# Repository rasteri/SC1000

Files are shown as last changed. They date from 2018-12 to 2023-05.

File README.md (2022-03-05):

# SC1000
## Open-source portable digital scratch instrument

This github holds source code and CAM files for the SC1000.

The SC1000 is a portable digital scratch instrument which loads samples and beats from a USB stick. At less than the size of three stacked DVD cases, it’s probably the smallest integrated portablist solution ever. Despite this, the software and hardware have been carefully tuned and optimised, and it’s responsive enough for even the most complex scratch patterns.

The device, including its enclosure, uses no custom parts apart from printed circuit boards. It will be possible for anyone with a bit of electronics know-how to build one, and I hope other makers in the portablist scene will be interested in manufacturing some.

The build tutorial video can be found here : https://www.youtube.com/watch?v=t1wy7IFSynY

## Usage ##

Simply switch on SC1000 with a valid USB stick in, and after a few seconds it will start playing the first beat and sample on the USB stick. Plug in some headphones or a portable speaker, adjust the volume controls to your liking, and get skratchin!

*Pressing* the **beat/sample down** button will select the next file in the current folder, and *holding* the button will skip to the next folder.

Note that you shouldn't touch the jog wheel while you are turning the device on - this is because the SC1000 does a short calibration routine. Leave it a few seconds before touching it.

## USB Folder layout ##

The SC1000 expects the USB stick to have two folders on it - **beats** and **samples**. Note that the names of these folders *must* be in all-lowercase letters.

The beats and samples folders should in turn contain a number of subfolders, to organise your files into albums. Each of these subfolders should contain a number of audio files, in **mp3** or **wav** format. For example, you might have a folder layout like : 

* beats/Deluxe Shampoo Breaks/beat1.mp3
* beats/Deluxe Shampoo Breaks/beat2.mp3
* beats/Deluxe Shampoo Breaks/beat3.mp3
* beats/Gag Seal Breaks/beat1.wav
* beats/Gag Seal Breaks/beat2.wav
* beats/Gag Seal Breaks/beat3.wav
* samples/Super Seal Breaks/01 - Aaaah.wav
* samples/Super Seal Breaks/02 - Fresh.wav
* samples/Enter the Scratch Game vol 1/01 - Aaaah Fresh.wav
* samples/Enter the Scratch Game vol 1/02 - Funkyfresh Aaaah.wav
* samples/Enter the Scratch Game vol 1/03 - Funkydope Aaaah.wav

Optionally, you can put an updated version of xwax on the root of the USB stick, and the SC1000 will run it instead of the internal version. This gives a very easy way to update the software on the device.

SC implementation chart

Demo Video (https://www.youtube.com/watch?v=ReuCnZciOf4)

The folders are as follows : 
* **Firmware** - Source code for the input processor. This handles the pots, switches and capacitive touch sensor, and passes the information on to the main processor.
* **OS** - SD card images and buildroot configs for the operating system that runs on the main processor.
* **Software** - Source code for the modified version of xwax running on the main SoC.
* **Hardware** - Schematics and gerbers for the main PCB and enclosure (which is made of PCBs)

## Tech Info ##

The device is based around the Olimex A13-SOM-256 system-on-module, which in turn uses an Allwinner A13 ARM Cortex A8 SoC. The sensing of the scratch wheel is handled by an Austria Microsystems AS5601 magnetic rotary sensor, and the other inputs are processed via a Microchip PIC18LF14K22 MCU. The whole unit is powered via USB, and optionally includes the ability to fit a power bank inside the enclosure.

## Build guide : 

### Assembly video ###

A video covering most of this information can be found at https://www.youtube.com/watch?v=t1wy7IFSynY

### Ingredients

* **Main PCB and components** - Board files are in [hardware](./hardware) and can be ordered from somewhere like https://jlcpcb.com/
* **Components** - Bill of Materials is in [hardware/](./hardware) and can be ordered from Mouser
* **A13 System-on-Module** - Available from https://www.olimex.com/Products/SOM/A13/A13-SOM-256/, connects to the main PCB via 0.05" headers
* **SD Card** - To hold the operating system. It only needs 200Mb so just get the smallest card you can find
* **Enclosure parts** - The enclosure is made from PCBs and aluminium supports. Gerber files are in *./hardware/gerbers/Enclosure/*, aluminium supports are 20x10x156.8mm. The front and rear plates should be 1mm thick, the rest should be 1.6mm. I got mine from https://www.aluminiumwarehouse.co.uk/20-mm-x-10-mm-aluminium-flat-bar, they even cut it for me.
* **Jogwheel parts** - The jogwheel itself is a gold-plated PCB, available in [hardware/gerbers/Jog Wheel](./hardware/gerbers/Jog%20Wheel). Mine is made from 0.6mm thick board, you can choose the thickness you prefer. You'll also need M8 bearing/hex bolt/nuts/washers, and a diametrically polarized magnet from https://www.kjmagnetics.com/proddetail.asp?prod=D42DIA-N52. The bearing I used is available at https://uk.rs-online.com/web/p/ball-bearings/6189957/
* **Mini innoFADER** - the OEM model (for example found in the innoFADER Mini DUO pack) is fine, but a Mini innoFADER Plus has  better performance

### Method ###

* **Order** the Main and Enclosure PCBs, the components, the A13 SoM, and SD Card, and the Aluminium bar. I recommend using ENIG coating for the Jogwheel as you don't really want to be touching solder all day.

* **Assemble the Main PCB.** I recommend assembling/testing the 3.3v power section first, so you don't blow all the other components. Don't connect the A13 module yet.

* **Flash the input processor with its firmware** through connector J8. You will need a PIC programmer, such as the Microchip Pickit 3. The firmware hex file is [firmware/firmware.hex](./firmware/firmware.hex)

* **Transfer the operating system to the SD card.** You will need an SD card interface, either USB or built-in to your PC. You can use dd on Linux/MacOS or Etcher on Windows to transfer the image. The image is [os/sdcard.img.gz](./os/sdcard.img.gz)

* **Insert the SD card in the A13 module, and attach the SoM to the main PCB.** Make sure it's the correct way round - the SD card should be right beside the USB storage connector on the rear of the SC1000.

* **Connect a USB power source, and power up the unit to test** - the A13 module's green light should blink a few times before remaining on.

* **Assemble the jogwheel** - glue the bearing into the hole in the top plate of the enclosure. Now glue the magnet to the tip of the M8 bolt. Attach the jogwheel to the bearing using the bolt/nut/washer. Solder a wire to the outside of the bearing to act as a capacitive touch sensor.

* **Connect** the fader to J1, capacitive touch sensor to J4, and (optionally) a small internal USB power bank to J3. If you don't use an internal power bank, put two jumpers horizontally across J3 to allow the power to bypass it.

* **Test** - copy some beats and samples to a USB stick, and see if they play. Check below for how to structure the folders on the USB stick.

* **Assemble the enclosure** - drill and tap M3 holes in the aluminium, and screw the whole enclosure together. Make sure the magnet at the end of the jogwheel bolt is suspended directly above the rotary sensor IC.

## License ##

Copyright (C) 2018 Andrew Tait <rasteri@gmail.com>

This program is free software; you can redistribute it and/or
modify it under the terms of the GNU General Public License
version 2, as published by the Free Software Foundation.

This program is distributed in the hope that it will be useful, but
WITHOUT ANY WARRANTY; without even the implied warranty of
MERCHANTABILITY or FITNESS FOR A PARTICULAR PURPOSE. See the GNU
General Public License version 2 for more details.

You should have received a copy of the GNU General Public License
version 2 along with this program; if not, write to the Free
Software Foundation, Inc., 51 Franklin Street, Fifth Floor, Boston,
MA 02110-1301, USA.

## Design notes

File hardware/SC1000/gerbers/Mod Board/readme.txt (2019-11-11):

This is a board to convert the v0.1 PCB to v0.2 by adding the required filters to the audio outputs.

It just solders directly underneath the 3.5mm audio jack.

You probably want to order it in thinner-than-normal PCB material (0.6 worked for me) and make sure your fab house can do castellated holes.

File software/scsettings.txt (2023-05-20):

#######################
# SC1000 config file #
######################
# Any lines beginning with # are ignored

###################
# General Options #
###################
#
# Fader thresholds for hysteresis
# You might need to adjust these for different faders
# faderopenpoint should always be 
# more than faderclosepoint

# Value required to open the fader when it's closed
faderopenpoint=5

# Value required to close the fader when it's opened
faderclosepoint=3

# 0 to disable platter, default 1 (enabled)
platterenabled=1

# Ratio of platter movement to sample movement
# 4096 = 1 second for every platter rotation
# 3072 = equivalent to 45rpm record (default)
# 2275 = equivalent to 33rpm
platterspeed=2275

# How long the stop button takes to stop the track
# Higher is longer, default = 3000
brakespeed=3000

# Pitch range % of pitch bend MIDI command, default 50%
pitchrange=50

# How long to delay before looking for MIDI devices
# Useful if your MIDI device takes a long time to initialize
# Or to give you time to switch your phone to MIDI mode
mididelay=5

# Set this to 1 or 2 to make the fader cut the beats
# 1 will cut on the left, 2 will cut on the right
cutbeats=0

####################
#   GPIO Mapping   #
####################
#
# This section is used to wire up buttons.
# These can be either directly wired to the Olimex module,
# or on an external MCP23017 GPIO expander
# Format is : 
# gpio=port,pin,pull,edge,action

# port is 0 for MCP23017, or 123456 for ports BCDEFG of A13 on Olimex
# pin number- for MCP23017, A0-A7 is 0-7 and B0-B7 is 8-15
# pull is 1 for pullup, 2 for pulldown
# edge is 1 for pressing edge, 2 for holding action, 3 for pressed while shifted, 4 for held while shifted, 0 for releasing edge
# action is one of :
# 
# (replace x with 0 for beats or 1 for samples) :
# CHx_CUE - Set and trigger cue points
# CHx_SHIFTON - Activate shift mode (ignores x)
# CHx_SHIFTOFF - Deactivate shift mode (also ignores x)
# CHx_STARTSTOP - Start or Stop the track
# CHx_NOTEy - Change the pitch musically, replace y with the note number (60 being 0%)
# CHx_GND - make the pin an output and set it low - used to provide additional ground connections (ignores x)
# gpio=port,pin,pull,edge,action

#### SC500 Buttons ####
# Detection pin
gpio=6,11,1,1,CH0_SC500

# Shift
gpio=2,9,1,1,CH0_SHIFTON
gpio=2,9,1,0,CH0_SHIFTOFF

# Beat Transport
gpio=2,14,1,1,CH0_PREVFILE
gpio=2,14,1,2,CH0_PREVFOLDER
gpio=2,14,1,3,CH0_RANDOMFILE

gpio=2,13,1,1,CH0_STARTSTOP

# even though this is on a beat button it still affects sample
gpio=2,13,1,3,CH1_JOGREVERSE

gpio=2,10,1,1,CH0_NEXTFILE
gpio=2,10,1,2,CH0_NEXTFOLDER
gpio=2,10,1,3,CH0_JOGPIT
gpio=2,10,1,0,CH0_JOGPSTOP

# Beat Volume Buttons
gpio=4,5,1,1,CH0_VOLUP
gpio=4,5,1,2,CH0_VOLUHOLD
gpio=4,4,1,1,CH0_VOLDOWN
gpio=4,4,1,2,CH0_VOLDHOLD

# Sample Transport
gpio=2,5,1,1,CH1_PREVFILE
gpio=2,5,1,2,CH1_PREVFOLDER
gpio=2,5,1,3,CH1_JOGPIT
gpio=2,5,1,0,CH1_JOGPSTOP

gpio=2,6,1,1,CH1_STARTSTOP
gpio=2,6,1,3,CH1_RECORD

gpio=2,8,1,1,CH1_NEXTFILE
gpio=2,8,1,2,CH1_NEXTFOLDER
gpio=2,8,1,3,CH1_RANDOMFILE

# Sample volume buttons
gpio=1,10,1,1,CH1_VOLUP
gpio=1,10,1,2,CH1_VOLUHOLD
gpio=1,4,1,1,CH1_VOLDOWN
gpio=1,4,1,2,CH1_VOLDHOLD

# Sample cue buttons
gpio=2,4,1,1,CH1_CUE
gpio=2,4,1,3,CH1_DELETECUE
gpio=2,7,1,1,CH1_CUE
gpio=2,7,1,3,CH1_DELETECUE
gpio=2,11,1,1,CH1_CUE
gpio=2,11,1,3,CH1_DELETECUE
gpio=2,12,1,1,CH1_CUE
gpio=2,12,1,3,CH1_DELETECUE

#### Expansion port J7 ####
gpio=6,10,1,1,CH0_SHIFTON
gpio=6,10,1,0,CH0_SHIFTOFF
gpio=1,15,1,1,CH0_STARTSTOP
gpio=1,16,1,1,CH1_STARTSTOP

gpio=2,3,1,1,CH1_CUE
gpio=2,0,1,1,CH1_CUE
gpio=2,2,1,1,CH1_CUE
gpio=2,1,1,1,CH1_CUE

gpio=2,3,1,3,CH1_DELETECUE
gpio=2,0,1,3,CH1_DELETECUE
gpio=2,2,1,3,CH1_DELETECUE
gpio=2,1,1,3,CH1_DELETECUE

#### MCP23017 Buttons ####
gpio=0,0,0,1,CH0_GND

gpio=0,1,1,1,CH1_CUE
gpio=0,2,1,1,CH1_CUE
gpio=0,3,1,1,CH1_CUE
gpio=0,4,1,1,CH1_CUE
gpio=0,5,1,1,CH1_CUE
gpio=0,6,1,1,CH1_CUE
gpio=0,7,1,1,CH1_CUE

gpio=0,1,1,3,CH1_DELETECUE
gpio=0,2,1,3,CH1_DELETECUE
gpio=0,3,1,3,CH1_DELETECUE
gpio=0,4,1,3,CH1_DELETECUE
gpio=0,5,1,3,CH1_DELETECUE
gpio=0,6,1,3,CH1_DELETECUE
gpio=0,7,1,3,CH1_DELETECUE

gpio=0,8,1,1,CH1_STARTSTOP
gpio=0,9,1,1,CH0_SHIFTON
gpio=0,9,1,0,CH0_SHIFTOFF 
gpio=0,10,1,1,CH1_CUE
gpio=0,10,1,3,CH1_DELETECUE
gpio=0,11,1,1,CH0_STARTSTOP
gpio=0,12,0,1,CH1_GND
gpio=0,13,1,1,CH1_CUE
gpio=0,14,1,1,CH1_CUE
gpio=0,15,1,1,CH1_CUE
gpio=0,13,1,3,CH1_DELETECUE
gpio=0,14,1,3,CH1_DELETECUE
gpio=0,15,1,3,CH1_DELETECUE

################
# MIDI Mapping #
################
#
# Format is :
# Status,channel,data,edge, action
# 
# Status can be : 
# 8 - Note OFF (will also match zero-velocity Note ON)
# 9 - Note ON
# 11 - Control Change
# 14 - Pitch Bend
#
# Channel is the MIDI channel of the incoming MIDI message
#
# Data is the note or CC number - set to "255" to bind to ALL notes of a particular channel
#
# Action can be (replace x with 0 for beats or 1 for samples) :
# CHx_CUE - Set and trigger cue points
# CHx_SHIFTON - Activate shift mode (ignores x)
# CHx_SHIFTOFF - Deactivate shift mode (also ignores x)
# CHx_STARTSTOP - Start or Stop the track
# CHx_PITCH - Change the speed of the track
# CHx_NOTEy - Change the pitch musically, replace y with the note number (60 being 0%)

#### LEMUR PRESET, normally hardcoded ####

# CC 0 of channels 0/1 is volume
midii=11,0,0,1,CH0_VOLUME
midii=11,1,0,1,CH1_VOLUME

# Pitch bend on channels 0 and 1 is pitch

midii=14,0,0,1,CH0_PITCH
midii=14,1,0,1,CH1_PITCH

# notes on channels 0 and 1 are cue points
midii=9,0,255,1,CH0_CUE
midii=9,1,255,1,CH1_CUE

# Also add the delete cue command for shift modifier
midii=9,0,255,3,CH0_DELETECUE
midii=9,1,255,3,CH1_DELETECUE

# Notes on channel 3 are C1-style notes
midii=9,3,255,1,CH1_NOTE

# Channel 4 has various other commands mapped to its notes
# Notes 0-1 = start stop
midii=9,4,0,1,CH0_STARTSTOP
midii=9,4,1,1,CH1_STARTSTOP

# Notes 2-3 = Next file
midii=9,4,2,1,CH0_NEXTFILE
midii=9,4,3,1,CH1_NEXTFILE

# Notes 4-5 = Next folder
midii=9,4,4,1,CH0_NEXTFOLDER
midii=9,4,5,1,CH1_NEXTFOLDER

# Notes 6-7 = Prev file
midii=9,4,6,1,CH0_PREVFILE
midii=9,4,7,1,CH1_PREVFILE

# Notes 8-9 = Prev folder
midii=9,4,8,1,CH0_PREVFOLDER
midii=9,4,9,1,CH1_PREVFOLDER

# Notes 10-11 = Random file
midii=9,4,10,1,CH0_RANDOMFILE
midii=9,4,11,1,CH1_RANDOMFILE

# Note 126 = record
midii=9,4,126,1,CH0_RECORD

# Note 127 = shift
midii=9,4,127,1,CH1_SHIFTON
midii=8,4,127,3,CH1_SHIFTOFF

# Status,channel,data,edge,action

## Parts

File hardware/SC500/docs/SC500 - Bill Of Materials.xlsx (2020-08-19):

 | Bill of Materials
 | SC500 Main PCB
Designator(s) | Qty | Manufacturer | Manufacturer Part Number | Description | Package | Type | Mouser Part Number
C1 | 1 | Taiyo Yuden | UMK316AB7475KL-T | Capacitor Ceramic 1206 4.7uF 16V X7R | 1206 | SMD | 963-UMK316AB7475KL-T
C2 | 1 | TDK | C3216X7R1C106M160AC | Capacitor Ceramic 1206 10uF 10v X7R | 1206 | SMD | 810-C3216X7R1C106M
C3, C4, C5, C6, C7, C8, C9 | 7 | Wurth Electronics | 885012208058 | Capacitor Ceramic 1206 0.1uF 10v X7R | 1206 | SMD | 710-885012208058
J1 | 1 | Amphenol FCI | 861400041LO1705LF | Connector Header 4x1 2.54mm RA | TH4X1 | THRU-HOLE | 649-86140041LO1705LF
J2 | 1 | Amphenol FCI | UE27AC54100 | Connector USB Type A | UE27AC54100 | THRU-HOLE | 523-UE27-AC54-100
J3 | 1 | Amphenol FCI | 68021-404HLF | Connector Header 2x2 2.54mm RA | TH2X2 | THRU-HOLE | 649-68021-404HLF
J4 | 1 | Amphenol FCI | 861400021LO1705LF | Connector Header 2x1 2.54mm RA | TH2X1 | THRU-HOLE | 649-86140021LO1705LF
J41, J43 | 2 | Amphenol FCI | 20021121-00010T4LF | Connector Header 2x5 1.27mm | SMT2X5 | SMD | 649-221121-00010T4LF
J42, J44 | 2 | Amphenol FCI | 20021121-00040T4LF | Connector Header 2x20 1.27mm | SMT2X20 | SMD | 649-221121-00040T4LF
J5 | 1 | Switchcraft | 35RAPC4BH3 | Connector 3.5MM Stereo Jack | 35RAPC4BH3 | THRU-HOLE | 502-35RAPC4BH3
J6 | 1 | TE Connectivity | 2108877-1 | Connector USB Type Micro-B | 2108877-1 | SMD + THRU-HOLE | 571-2108877-1
L1 | 1 | Taiyo Yuden | NR6028T2R2N | Inductor 6028 2.2uH 3.7A 26mOhm | 6028 | SMD | 963-NR6028T2R2N
R10, R11, R12, R13, R14 | 5 | Yageo | RC1206JR-134K7L | Resistor 1206 4.7K 1/4W 20% | 1206 | SMD | 603-RC1206JR-134K7L
R4, R6, R17 | 3 | Yageo | AC1206FR-0722RL | Resistor 1206 22R 1/4W 1% | 1206 | SMD | 603-AC1206FR-0722RL
R2 | 1 | Yageo | RC1206FR-07442KL | Resistor 1206 442K 1/4W 1% | 1206 | SMD | 603-RC1206FR-07442KL
R3 | 1 | Yageo | RC1206FR-07100KL | Resistor 1206 100K 1/4W 1% | 1206 | SMD | 603-RC1206FR-07100KL
S1, S2, S3, S4, S5, S7, S8, S9, S10, S11, S12 | 11 | TE Connectivity | FSM14JLH | Switch Tactile | FSM14JLH | THRU-HOLE | 506-FSM14JLH
S13, S14 | 2 | E-Switch | TL2243 | Switch Dual SPST, Dual | TL2243 | THRU-HOLE | 612-TL2243
U1 | 1 | ams | AS5601-ASOM | IC Rotary Sensor SOIC-8 | SOIC8 | SMD | 985-AS5601-ASOM
U2 | 1 | Texas Instruments | TLV62568DBVR | IC Buck Converter SOT23-5 | SOT-23-5 | SMD | TLV62568DBVR
U3 | 1 | Microchip | PIC18LF14K22-I/SO | IC MCU PIC18 | SOIC20 | SMD | 579-PIC18LF14K22I/SO

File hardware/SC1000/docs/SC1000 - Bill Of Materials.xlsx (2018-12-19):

 |  | Bill of Materials
 |  | SC1000 Main PCB
Item # | Designator(s) | Qty | Manufacturer | Manufacturer Part Number | Description | Package | Type | Mouser Part Number
1 | C1 | 1 | Taiyo Yuden | UMK316AB7475KL-T | Capacitor Ceramic 1206 4.7uF 16V X7R | 1206 | SMD | 963-UMK316AB7475KL-T
2 | C2 | 1 | TDK | C3216X7R1C106M160AC | Capacitor Ceramic 1206 10uF 10v X7R | 1206 | SMD | 810-C3216X7R1C106M
3 | C3, C6, C7, C8 | 4 | Wurth Electronics | 885012208058 | Capacitor Ceramic 1206 0.1uF 10v X7R | 1206 | SMD | 710-885012208058
4 | J1 | 1 | Amphenol FCI | 861400041LO1705LF | Connector Header 4x1 2.54mm RA | TH4X1 | THRU-HOLE | 649-86140041LO1705LF
5 | J2 | 1 | Molex | 48204-0001 | Connector USB Type A | 48204-0001 | THRU-HOLE | 538-48204-0001
6 | J3 | 1 | Amphenol FCI | 68021-404HLF | Connector Header 2x2 2.54mm RA | TH2X2 | THRU-HOLE | 649-68021-404HLF
7 | J4 | 1 | Amphenol FCI | 861400021LO1705LF | Connector Header 2x1 2.54mm RA | TH2X1 | THRU-HOLE | 649-86140021LO1705LF
8 | J41, J43 | 2 | Amphenol FCI | 20021121-00010T4LF | Connector Header 2x5 1.27mm | SMT2X5 | SMD | 649-221121-00010T4LF
9 | J42, J44 | 2 | Amphenol FCI | 20021121-00040T4LF | Connector Header 2x20 1.27mm | SMT2X20 | SMD | 649-221121-00040T4LF
10 | J5 | 1 | Switchcraft | 35RAPC4BH3 | Connector 3.5MM Stereo Jack | 35RAPC4BH3 | THRU-HOLE | 502-35RAPC4BH3
11 | J6 | 1 | TE Connectivity | 2108877-1 | Connector USB Type Micro-B | 2108877-1 | SMD + THRU-HOLE | 571-2108877-1
12 | L1 | 1 | Taiyo Yuden | NR6028T2R2N | Inductor 6028 2.2uH 3.7A 26mOhm | 6028 | SMD | 963-NR6028T2R2N
13 | R1, R7, R8, R9, R10, R11, R12, R13, R14 | 9 | Yageo | RC1206JR-134K7L | Resistor 1206 4.7K 1/4W 20% | 1206 | SMD | 603-RC1206JR-134K7L
14 | R2 | 1 | Yageo | RC1206FR-07442KL | Resistor 1206 442K 1/4W 1% | 1206 | SMD | 603-RC1206FR-07442KL
15 | R3 | 1 | Yageo | RC1206FR-07100KL | Resistor 1206 100K 1/4W 1% | 1206 | SMD | 603-RC1206FR-07100KL
16 | R5, R15 | 2 | Bourns | PTV09A-2020S-B104 | Potentiometer 100K | PTV09A | THRU-HOLE | 652-PTV09A2020SB104
17 | S1 | 1 | E-Switch | PB400EEQR1BLK | Switch DPST | PB400 | THRU-HOLE | 612-PB400EEQR1BLK
18 | S2, S3 | 2 | E-Switch | TL2243 | Switch Dual SPST, Dual | TL2243 | THRU-HOLE | 612-TL2243
19 | U1 | 1 | ams | AS5601-ASOM | IC Rotary Sensor SOIC-8 | SOIC8 | SMD | 985-AS5601-ASOM
20 | U2 | 1 | Texas Instruments | TLV62568DBVR | IC Buck Converter SOT23-5 | SOT-23-5 | SMD | TLV62568DBVR
21 | U3 | 1 | Microchip | PIC18LF14K22-I/SO | IC MCU PIC18 | SOIC20 | SMD | 579-PIC18LF14K22I/SO

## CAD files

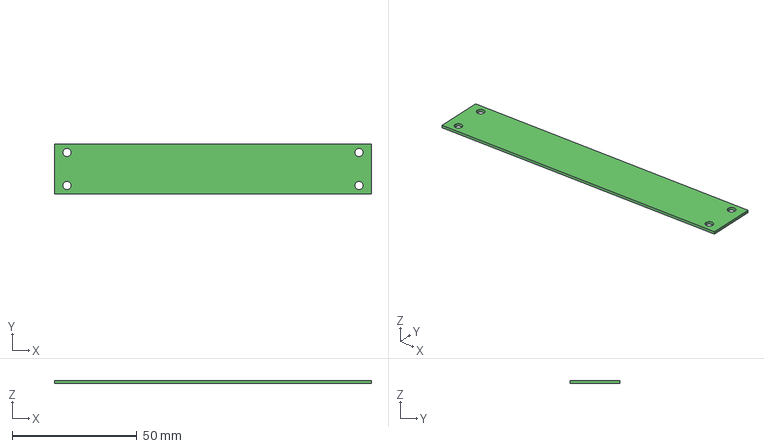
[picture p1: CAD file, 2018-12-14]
hardware/SC1000/step/frontplate.step
126.8 x 20.0 x 1.05 mm

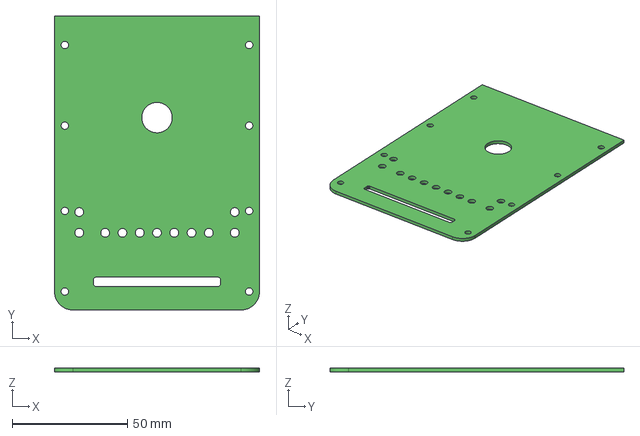
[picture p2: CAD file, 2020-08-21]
hardware/SC500/step/TOPPLATE.step
89.0 x 127.6 x 1.65 mm

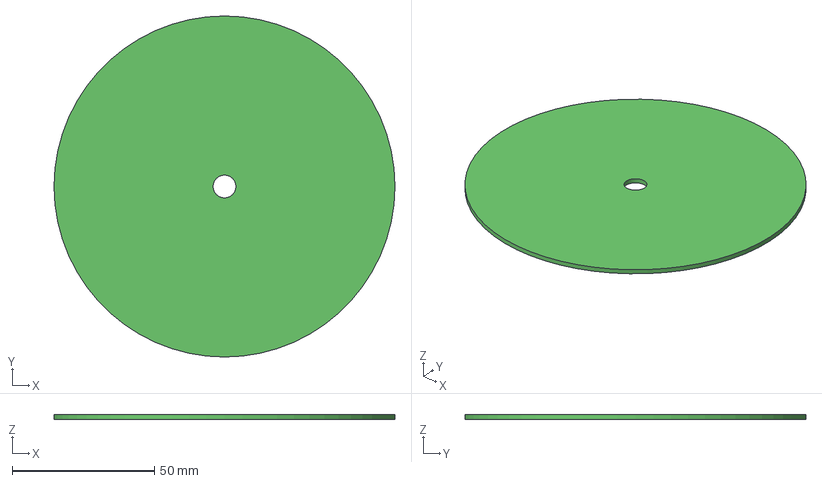
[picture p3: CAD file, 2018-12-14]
hardware/SC1000/step/jogwheel.step
120.0 x 120.0 x 1.65 mm

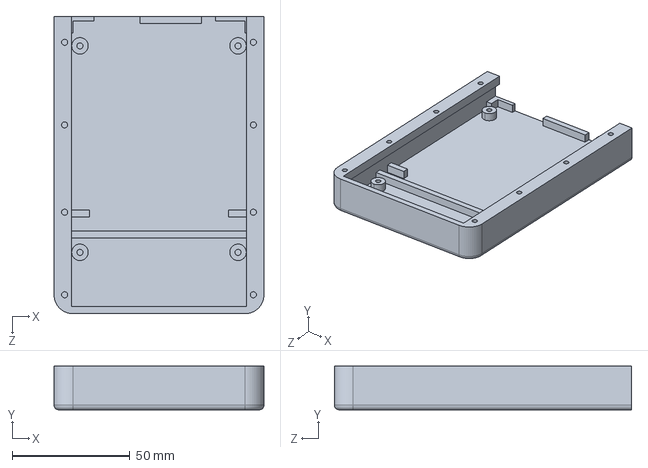
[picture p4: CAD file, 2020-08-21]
hardware/SC500/step/enclosure.STEP
89.0 x 18.5 x 126.0 mm

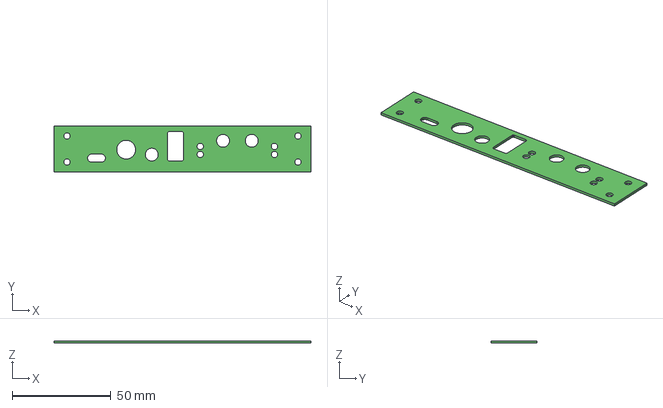
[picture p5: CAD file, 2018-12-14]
hardware/SC1000/step/backplate.step
130.0 x 23.2 x 1.12 mm

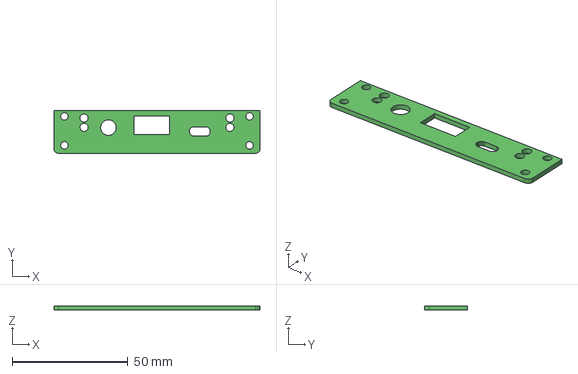
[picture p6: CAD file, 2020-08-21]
hardware/SC500/step/BACKPLATE.step
89.0 x 18.5 x 1.72 mm

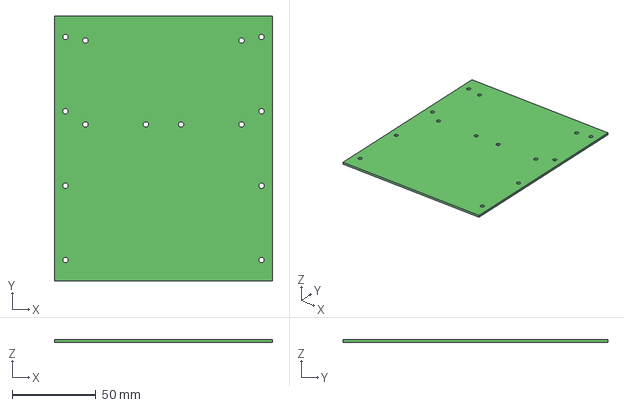
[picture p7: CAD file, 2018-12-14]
hardware/SC1000/step/bottomplate.step
130.0 x 157.8 x 1.65 mm

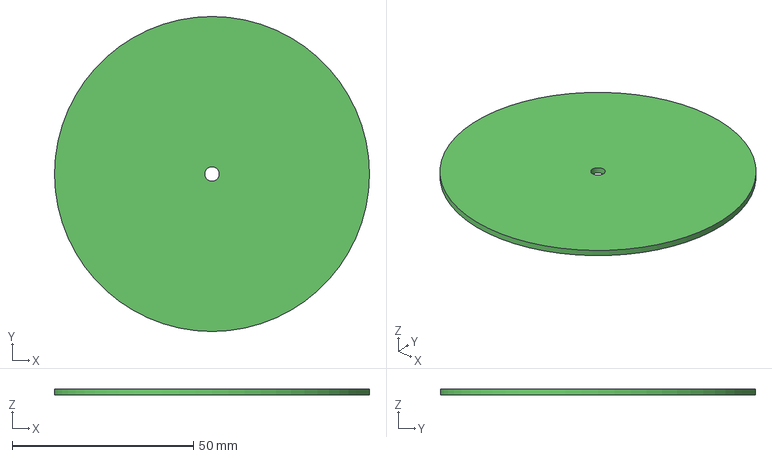
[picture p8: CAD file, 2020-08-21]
hardware/SC500/step/JogWheel.step
87.0 x 87.0 x 1.65 mm

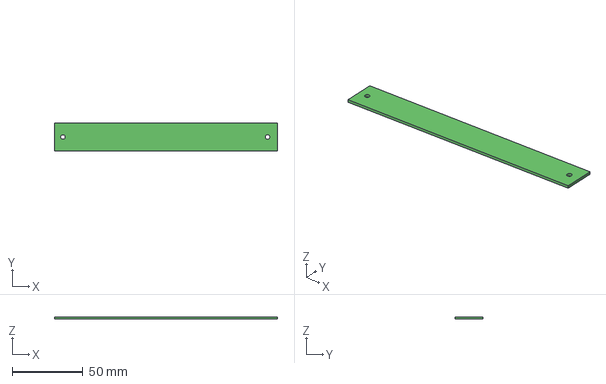
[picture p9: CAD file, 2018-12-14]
hardware/SC1000/step/sideplate.step
157.8 x 20.0 x 1.65 mm

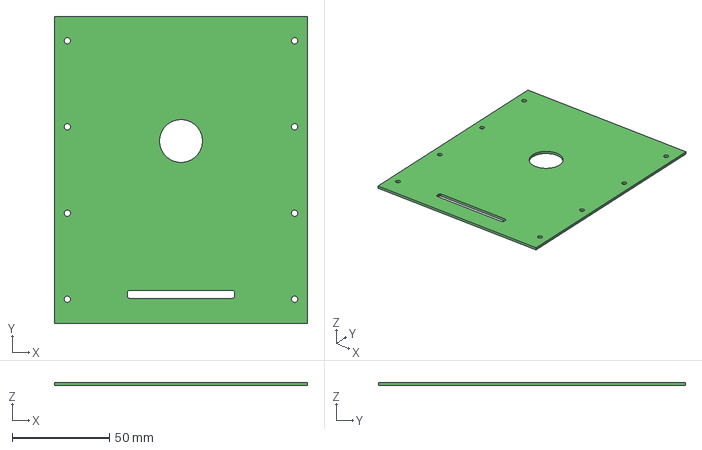
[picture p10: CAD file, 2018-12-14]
hardware/SC1000/step/topplate.step
130.0 x 157.8 x 1.65 mm

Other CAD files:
hardware/SC500/enclosure.STL

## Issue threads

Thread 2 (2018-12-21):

Jog Wheel PCB Dimensions

markprotas, 2018-12-21:
The dimensions of the jog wheel are a mystery to me- viewing the gerber files and attempting to run some dimension analysis on them, it seems like I get something like 1200 x 1200 mm, which certainly doesn't make any sense given the nature of the machine.  How can I figure out the actual jog wheel dimensions for fabrication?

rasteri, 2018-12-21:
It's 120mm X 120mm.

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

Closed 2019-09-09.

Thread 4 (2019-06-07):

No RC to ground filtering on headphone lines

DanKoloff, 2019-06-07:
Hello,

Lub from Olimex here. In your schematic I can see that there are no RC to ground groups on HPCOM and HPOUTL and HPOUTR. This might cause issues with some headphones or other audio equipment. Did you omit such on purpose?

Please perform some tests. Use the A13-OLinuXino-WIFI design as basis of the groups (left side of the schematic): https://github.com/OLIMEX/OLINUXINO/blob/master/HARDWARE/A13-OLinuXino/A13-OLinuXino_WIFI_Rev_H.pdf

I've also cut it out here:
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

Lub/OLIMEX

rasteri, 2019-06-07:
Hi Lub, good to hear from you.

Yes this was an oversight, but this was just really a development board to test software etc. As you say, there is some noise on the headphone output, particularly when the device is unpowered. I'm doing a second board revision with these changes plus some other stuff (ESD protection, better capacitive touch sensing).

Thanks for your input - if you notice any other problems let me know.

s3kn0tr0n1c, 2019-06-19:
Thanks for referring me to this after I contacted you about headphones out @DanKoloff .

I will modify my board this week as Im back from holiday and let you and @rasteri  know how it goes.

@rasteri  - Im the guy who you got to do the special firmware without touch sensor for. I have a couple of other minor issues that I'm sure you can fix too ;).

s3kn0tr0n1c, 2019-06-20:
Hi, Heres some of my current mods. Ive added the caps/resistors to output. Will check it out properly over next few days. See if there's any improvement plugging into line ins etc.  Here's a picture of mod you can refer others to if they want to see how I did it. Basically soldered a resistor to headphone pin, cap to resistor x3 . Then soldered 1 wire from nearby GND to all the caps.
-
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

I also added an area for my USB battery to be held so that unit can be an "all in one" unit. Heres how I did this using PCB spacers-

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

Also see this video showing battery mod.  - https://youtu.be/33W1NoMLeOI

After that I redone the side panels so finished item is like this -

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

Its now a nice little all in one unit self powered( a little thicker but no messy wires or USB battery hanging about) . All I gotta do is plug in headphones. Sweet.

s3kn0tr0n1c, 2019-06-20:
Now onto bug you @rasteri ;) Heres some issues(remember I'm on the "no touch sensor build")

1) When I load a new sample there is a distortion noise until I move the platter. You also get this if you go outwith the sample start/end points. Its quite extreme lol.

2) If you move the xfader to the cut in point. Like right  between off/on you get this weird effect where you are hearing the sample playing but robotic like. Im not sure if this has anything to do with my next issue, perhaps causing a bug.

3) Sticker drift. My reason for no touch sensor was to preserve the samples position to red marker on record. After a few fast movements and going round a full turn etc the sample no longer is at same position when you rewind record.

4) Not reloading sample when you change to it. Its like the sample is still stored in memory from before and plays from this position. It would be much better if it was reset/reloaded to play from the start again.

If 3 and 4 were sorted then I would be able to move record to 12oclock. Load in new sample and the samples would always be at same position , as they are on a regular record. (or on seratos -"sticker lock" feature, which is great.)

Must say if you could get these last things sorted this toy is GODLIKE ;).

Also I just discovered if you cut a beat correctly it auto loops as well. Ive been chopping 8-32 bar loops and they play like any skratch looper. Brilliant. Love it.

s3kn0tr0n1c, 2019-06-20:
Also I just used a standard ball bearing this time and hot melted it in place. Not sure if how well it will stay in place. Should be fine if i never sit on it lol.

Anyways FYI - you get flanged bearings that would be better that I may switch to later-

https://www.ebay.co.uk/itm/PREMIUM-MODEL-BEARINGS-FLANGED-TYPE-2RS-ZZ/200709759794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

These would also be easier to get to sit perfectly flat. Worth thinking about for future build guides ;)

s3kn0tr0n1c, 2019-06-20:
Ive did a video showing the bugs -

https://youtu.be/wtL78jQTReM

rasteri, 2019-09-09:
I have updated the schematics and gerbers to include the filters, and designed a mod board so this can be retro-fitted to the original dev boards.

The latest firmware rev also fixes the issues s3kn0tr0n1c talked about - available here
[sc1000previewbuild.zip](https://github.com/rasteri/SC1000/files/3591641/sc1000previewbuild.zip)

Closed 2019-09-09.

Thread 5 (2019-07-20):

Screws for USB connector J6

schmitts, 2019-07-20:
Which screw type is to use for the USB connector J6?

s3kn0tr0n1c, 2019-07-24:
I used M1.6mm. I bought them and the  nuts of ebay.

https://www.ebay.co.uk/itm/321168183114
https://www.ebay.co.uk/itm/111309628000

rasteri, 2019-09-09:
I used M1.4 screws and nuts. Best get em from ebay.

Closed 2019-09-09.

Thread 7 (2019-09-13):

Loud Static Bursts in XWAX

wowitsjack, 2019-09-13:
Scratching from the very beginning of a sample can often lead to horrific max volume static.

rasteri, 2019-09-13:
Have you tried the latest firmware? http://rasteri.com/sc1000previewbuild.zip

10shun, 2019-10-06:
Hello the link you supplied for the latest firmware is dead link. can you upload the latest firmware on GitHub or provide a new link?

rasteri, 2019-10-09:
sorry, I hadn't paid my host this month :) it should be back now

microfx, 2021-08-06:
I copied both files over ...I hear a change in that annoying buzzing sound (a shame that my shiny new prebuilt device has that problem) but it doesn't boot sadly.

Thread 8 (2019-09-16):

New firmware feedback

s3kn0tr0n1c, 2019-09-16:
Thanks Rasteri for addressing the issues with the new firmware. This thing totally rocks now. Loving the custom settings you can choose from. Ive gave mine a good cut session with new firmware and all my issues have been resolved. Massive thanks.

I did notice a couple of times when fader was open(sample on) it sounded a little robotic, sort of like the sound I got on original firware when fader was in the cut zone. Moving the fader back to "off" cleared it. This only happened a couple of times in quite a long session so Im not too bothered tbh. All in all really good work. This defo the best portable scratching device out ther now.

Ive done some cut session videos. Feel free to share them on any of your SC1000 pages on social media. I dont do social media or I'd post them in there.

https://www.youtube.com/watch?v=ECYCsCCTnXI

https://www.youtube.com/watch?v=CgwY-1ddHic

https://www.youtube.com/watch?v=ACjyi4h--4Y

Once again thank you.

rasteri, 2019-09-16:
Cool! I'll keep an eye out for that bug you mentioned. Let me know if you manage to catch it on video.

schmitts, 2019-12-13:
With the new firmware, the scratch sample does not loop anymore, correct?

10shun, 2019-12-15:
> With the new firmware, the scratch sample does not loop anymore, correct?

Yeah it seems the scratch samples don't loop anymore. Is there a setting we can do make them loop again?

rasteri, 2019-12-18:
No it doesn't loop anymore. I'll find a solution for that.

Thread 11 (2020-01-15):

Main PCB revision - RFC

technotion, 2020-01-15:
Request for comment. Move the potentiometer circuits and through holes approx. 2.3-3mm closer to the edge of the board. This will allow for a wider range of audio knobs to be used. At current with the standard 1.6mm thick enclosure back plate there is only 5.4mm of shaft available on the potentiometers. Optimally we would need 7.75mm or more.

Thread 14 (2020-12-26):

SC500 image

ximo23, 2020-12-26:
Hi,
I have mounted a SC500 and when I try to run the SD Image posted in the repository it doesn't work properly, it behavies like a SC1000. The problem is that the buttons map is different and I can't change de volume, the beat or the sample.
I think that I can solve the problem updating de firmware, the only way that I found is like in this video, but the button map is different and there are not potentiometers in SC500:
https://www.youtube.com/watch?v=4zC_MFa_150&t=50s

How can I prepare a correct SD image for the SC500? It's possible to do a firmware update overwriting the sistem files with the new software?
http://rasteri.com/ website is not working now, maybe this informatin is there.

Someone can share a valid SD image for the SC500?

Thanks

rasteri, 2020-12-30:
You need to update to the latest image. Update procedure for the 500 is the same as the 1000, but you hold down the beat VOL button instead of the beat track select button.

Closed 2020-12-30.

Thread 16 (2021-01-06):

SC500 - sound levels + recording + multitrack?

ffd8, 2021-01-06:
Finally got to play with an SC500! Here's a couple issues I ran into while recording:

I have headphones plugged directly into the AUX jack, but it's super loud on bootup and both sample/beat volumes need to be reduced a few steps. Learning there is no headphone/out volume? Since adjusting these levels also seems to affect their levels on the recording. Would be awesome if holding shift then either sample or beat would adjust the aux out level (or eventually have an analog poti). Also really helpful if these three levels could be set in the `settings` so it remembered it on power up/down.

#### recording
Is it a bug/feature that the BEEEEEP for starting/stopping a recording is WAAY louder than the set volume for beat/samples? Kinda killed my headphone ears the first time.. nice if it too used the volume of samples or better yet, had an option to have only a visual-beep (for those using clear cases where the microcontrollers LED is visible). Could that LED be used to indicate recording? (blinking = recording in progress, few fast blinks = saving, static = normal mode)... maybe I'm just still traumatized by that first beep...

#### raw file date
The date on the saved file's is `Jan 1, 1980, 00:00` – normal? does it lack an internal clock?

#### copying raw file
With my first recording, ran into this issue (had waited long after the finishing rec beeps),
trying to copy the raw file from the SD card to my computer, MacOS 10.13.6 gave an error:
```
The Finder can’t complete the operation because some data in “sc000000.raw” can’t be read or written.
(Error code -36)
```
Using `cp` in CLI worked, but gave me a warning:
`>>> cp /Volumes/NO\ NAME/sc000000.raw ./`
`cp: /Volumes/NO NAME/sc000000.raw: Argument list too long`
 (which I don't think has anything to do with file?)

A second recording copied fine from the SD card.

#### opening raw file
Searching portablismgear + this repo, couldn't find any details about raw import settings the .raw recording into Audacity..
(then found your youtube v1.3 firmware update vid). The suggested audacity raw import options changed (between that first funky file and 2nd better one), so for future folks reference, here's the import settings:
```
Encoding: Signed 16 bit PCM
Byte Order: Little-endien
Channels: 2
Start offset: 0
Amount to import: 100%
Sample rate: 48000
```

#### multi-track recording?
When learning it was a raw file, was optomistic it would be a multi-track recording. Is that possible?? Would be awesome to save a 4 track recording, scratched samples + beats separate. Then one could always fix the levels later. Again, tricky my recording came in so quiet because I needed to lower the volume so much at startup.

h-david-a, 2021-02-02:
I was wondering is it possible to implement live input. E.g via USB audio interface

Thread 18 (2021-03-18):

Dual AS5601 implementation isn't possible?

DubbyLabby, 2021-03-18:
Hi Andy,
I was looking at datasheet for the part and I can't see if it's possible to set a dedicated i2c address for the part so it will be impossible to add another to control the second layer... right?

DubbyLabby, 2021-05-13:
Possible is but it will need some coding and some soldering.
Also take in consideration Olimex have only one stereo output so as-is it wouldn't be used for external mixing.

IDK if Olimex board could handle class compliant audio interface as raspberry pi. Maybe just a matter of code... that way this second trouble could be workarounded (lol)

Closed 2021-07-16.

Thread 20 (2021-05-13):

CPL pick&place file for sc500

DubbyLabby, 2021-05-13:
Hi Andy,
I noticed you have the CVS file for sc1000 but not for sc500. I'm trying to calculate how much it will cost to send jlcpcb for some ready units but not luck.

Can you advise me somehow?

Thanks

DubbyLabby, 2023-04-21:
Not completed but neither needed anymore...

flintspike, 2024-12-10:
This is a pretty old comment, but I dont suppose you have either of those files?

DubbyLabby, 2024-12-10:
Hi!
If you read my previous comment you will notice that never happened… but also I don’t need them neither.

Sorry mate 🙏🏻

Closed 2023-04-21.

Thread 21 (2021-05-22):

SC1000 MK2 remapping buttons

ivogrig, 2021-05-22:
Hi Rasteri,

https://portablismgear.com/pub/media/catalog/product/cache/ac998914e31a39cd2b069df358c53945/s/c/sc1000mk2_mirror_red_1.jpg

I bought a ready-made SC1000 MK2 from portablismgear.com and I would like to swap the STARTSTOP button with the first CUE button. (It has four CUE buttons on the top and the SHIFT / STARTSTOP on the front-side)

I tried copying the sections from the scsettings.txt file into the one on my usb-stick and messing with the settings but I could not figure it out, the buttons stop functioning. I also tried the Olimex settings from the scsettings.bak file.

The way I understand it, the Olimex GPIOs are the built-in ones and then there is the external MCP23017.
I have no idea which one is used in the the SC1000 MK2.
Is there an easy way to find the corresponding pin numbers via software, without opening the hardware box?

Where in the code is the settings file being parsed and what are the default pin-settings for the SC1000, does it happen here?
https://github.com/rasteri/SC1000/blob/master/software/sc_input.c#L147

Sorry to bug you about this.

Best,
Ivo

DubbyLabby, 2021-05-31:
Schematic could help you understand the function of the pic and what pins are directly pointing the Olimex.
https://github.com/rasteri/SC1000/blob/master/hardware/SC500/docs/SC500%20-%20Schematic.PDF

The pic takes care of xfader, pot 1&2 and capacitive sensor.

I read all the config files (and the code behind) but I can't remember if just swapping the pin values will be enough so it could be an error or not. I should look again into these files to bring some more help but meanwhile let's hope Andy puts some light into it.

This is the main.c code for the pic
https://github.com/rasteri/SC1000/blob/master/firmware/main.c

Here there are some pin mapping on sc500, maybe will help you in your quest. I also get bogus with too many C and complex syntax like those...
https://github.com/rasteri/SC1000/blob/master/software/sc_input.c

Here mapped functions
https://github.com/rasteri/SC1000/blob/master/software/sc_midimap.h

I hope it helps somehow...

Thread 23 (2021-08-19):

sc1000ds

errolkokbas, 2021-08-19:
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

It is very hard to find information about this version anywhere online. It is possible to mod an existing sc500/sc1000/sc1000mk2 to have a screen?

I'm especially interested in the idea of having some sort of visual feedback, as seen in this instagram video:

https://www.instagram.com/p/B0BWULPAqTg/

Even if it were a ring of LEDs around the platter instead of a screen, or maybe even a motorized platter? What are the limits of what is possible with this device, especially if/when it becomes a class compliant midi controller itself? The arcade button for play/pause and the encoder for track select really round out the controls.

My dream device would be sc500 sized, class compliant midi controller mode, LED light ring around jogwheel. I love having all those extra buttons on the top of the sc500, having access to them in midi controller mode would allow you to have all sorts of hotcues, play/pause, cue, shift, sync etc. mapped in your software of choice.

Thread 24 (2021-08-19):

jogwheel edge/tempo nudge

errolkokbas, 2021-08-19:
Would it be possible to implement some sort of nudging logic to the jogwheel if no touch is detected? This way you could make the outside edge of the platter non-conductive somehow, like perhaps removing some of the gold platting on the pcb around the outer edge, to facilitate using the nudge logic without the need for any other button presses.

To be clear, what I mean by nudge is that when you move the jog wheel, the tempo changes briefly, with a rapid but gradual change, and then goes back to what it was again. This is super useful for beat matching tracks, and would compliment the pull request for LED ring indicators nicely, more and more like a real turntable. (I really want to use two sc500's with a serato timecode signal audio file for dvs)

rasteri, 2021-08-21:
Yeah like how a CDJ works, I getcha. I'll possibly implement it in a future release.

errolkokbas, 2021-08-21:
Just curious, would this be strictly a firmware update, besides making a non-conductive outside edge on the platter? I am thinking it could even be done by applying a layer of paint or something similar. I am wondering because I want to know if I should wait for a new board revision or other changes to the hardware, before I buy a set of sc500's. Or, could I go ahead and get them now and just update them in the future?

errolkokbas, 2021-08-21:
Just curious, would this be strictly a firmware update, besides making a non-conductive outside edge on the platter? I am thinking it could even be done by applying a layer of paint or something similar. I am wondering because I want to know if I should wait for a new board revision or other changes to the hardware, before I buy a set of sc500's. Or, could I go ahead and get them now and just update them in the future?

errolkokbas, 2021-08-21:
Whoops, didn't mean to close this issue, still learning github over here....my browser loaded the page with the text of my previous post duplicated in the comment box, I thought I was clearing that.

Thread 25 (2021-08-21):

May I suggest SHIFT+Start to Play/Stop the beat?

SaccoSVD, 2021-08-21:
Would be nice to do that in the same way you can start/stop the sample "platter"

That in order to not have to adjust volumes all the time. (Yes I'm aware I can cut the beat with the fader in v 1.7Alpha)

Thank you :)

rasteri, 2021-08-21:
You could actually add this yourself. I think the following line should work (in 1.7 anyway) if you add it to scsettings.txt

`gpio=1,16,1,3,CH0_STARTSTOP`

I can't test it just now but let me know if it works

SaccoSVD, 2021-08-21:
Niiiice! it does graciously works!

Thank you!

Closed 2021-08-21.

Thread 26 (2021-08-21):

Mapping 2 CUE buttons as pitch semitone up/down

SaccoSVD, 2021-08-21:
Can I do that through the settings file?

Would like to be able to alter the sample pitch quickly by semitones by using CUE3 and CUE4

Sorry I write this here, cause is not really an "issue". I wonder if there's a forum for tips and general help. Like for example having a list all the possible things (commands) doable through the settings file.

It is very hard to figure out by myself what the numbers do in for example: **gpio=1,16,1,3,CH0_STARTSTOP** (I did look in some of your PDFs but cannot make heads or tail)

I'm using my SC1000MK2 in studio situations to record scratches over my compositions. (film / series music)

BTW: It  would be truly awesome if you made the SC500 / 1000MK2 to act as a USB controller for a VST sampler (scratcher) plugin so you can record/edit automation or swap samples to an existing recorded automation. That would also help being able to see where in the sample you're located precisely.

DubbyLabby, 2021-08-23:
Check this
https://www.stagecraftsoftware.com/products/scratchtrack/

also this
https://youtube.com/channel/UCS4W_KVRc0tQcRQht16EhLQ

SaccoSVD, 2021-08-23:
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

Ohhh of course! how did I not think about that, I can use a timecode audiotrack right?

DubbyLabby, 2021-08-23:
Just get a midi enabled mixer for the xfader.

SaccoSVD, 2021-08-23:
Mmm...not an option for me. Having an extra piece of gear just for the fader seems real clunky.

Perhaps the fader in the SC1000 can actually be read and possibly could be sent out via USB as MIDI data.

DubbyLabby, 2021-08-23:
It’s possible and Andy stated he’s interested on implement it but it will take some time. How long will depend on him or someone else willing to do that implementation.

Cheers

SaccoSVD, 2021-08-23:
Ooooh! That's great!!

SaccoSVD, 2021-08-24:
> Check this
> https://www.stagecraftsoftware.com/products/scratchtrack/

Tried that VST. I have the serato "control CD.wav" and also Deckadance's "control_cd.wav"

None worked with this VST. The VST itself kinda looks promising but it failed on me, too clunky and also made FL to "poof!" without a warning. So, another nono.

I tried Deckadance and worked "well", all functioned great but for some reason, internally there is enough latency even at 32 samples in my interface, it resulted in a rubberband feeling, not usable for scratching.

I think at this point the best is to add a LED ring so you can enjoy ultra low latency scratching directly from the SC1000

SaccoSVD, 2021-08-24:
There you go!! MsPinky timecode and Pinky VST works flawlessly. 🗡️🗡️ 🗡️

https://youtu.be/qVfssqPZxBI

DubbyLabby, 2021-08-24:
I think serato cd snd deckadance control cd aren’t supported. The first probably the old (mk1) tone signal and the deckadance probably propietary tone so both required special library for working (I’m not sure 100% but I believe djplayer has the same issue and overrides it with “timecode learn” using only relative mode from setting up the Hz manually).
Ms. Pinky is another history because Aaron Leese was active at forums back in the day and also I pointed him some of the features when the softepware was called livetronika studio.

It also support midi so if SC project gets midi/hid out you can ditch the timecode middle step and just focus on perform.

cheers.

SaccoSVD, 2021-08-24:
> It also support midi so if SC project gets midi/hid out you can ditch the timecode middle step and just focus on perform.

That would be truly awesome. :D Next level SC1000

DubbyLabby, 2021-08-24:
In fact will be previous level. Old scratchbox rasteri’s project did that back in the day and new could had seen as better since as you noticed it’s possible to just load a timecode to make it work with any dj app out there. The main issue about midi/hid was ever the lack of software capable to get use of regular midi for scratch control (song playhead) so going timecode was the only possible option to keep things compatible. That’s why Denon released hybrid mode and that why Denon Prime are standalone but compatibility with Traktor/Serato cames as “extra” (and usually requires dealing a fee between parts.
The good side of nowadays it’s Vdj, Djplayer pro and scratch track plugin as 3 true options that weren’t available back in the day. Aside of them, it will not be possible control that “playhead” without timecode since Traktor/Serato still not leave that control (properly) from Midi (afaik) and I have no clue about Rekordbox (but I expect the same).

OT end.

errolkokbas, 2021-08-31:
So having just gone through the settings file and not understanding most of it; I have some similar questions to the OP here.

Is it possible to use the fader to control any functions other than cutting the sample? I'm thinking about trying to map the pitch bending control to the fader. Holding down shift would switch the fader into pitch control, and the pitch would be 0% in the middle and +/-50% on either end of the fader throw, and would stay at that pitch setting when you release the shift button.

Even typing this out, with my limited understanding of the settings file, I feel like this is beyond the scope of the settings....but I just don't know enough about this stuff....

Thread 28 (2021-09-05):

Can this be put on a raspberry pi 4?

audovoice, 2021-09-05:
**The Sc1000 is amazing in its simplicity, affordability, and performance.
But I am confused about how it works.**
The firmware code seems to just be about configuring and reading the magnetic rotary sensor and crossfader. Is that right?

Then I came across http://xwax.org/ and was looking at that code before I even realized that was what was in the OS folder this project.

**What if any modification did were made to xwax to make it work with the sc1000 device?**
There is a project that puts xwax on a pi 3 but it still uses digital vinyl.
https://pideck.com/

**It seems like one need only jump into the code for xwax after the point it has turned the input stream of audio from jack into a timecode.** possibly in timecoder.c or player.c

**Or does the sc1000 just make a digital vinyl input stream for xwax?** If so is that efficient?

Anyway I am looking into all this because I'd like to try adding features. I'd like to mix in live loop recording. Recording a loop and then getting that into the sc1000 to scratch it. I saw someone make a simple but effective looper with a pi 4.
https://www.youtube.com/watch?v=S_rkdmCzIO0&t
But with a separate device they would need a shared memory.

I see that xwax does have rudimentary live loop recording functionality by loading a file with .live as the file type.

Ultimately I am asking how hard would it be to do something like this project with a crossfader and magnetic rotary sensor, but on a raspberry pi 4.

DubbyLabby, 2021-09-08:
I will suggest you to get djplayer pro on ol iPhone if you aren’t prone to code by yourself.
Money wise isn’t so expensive in comparision (rpi, screen, audio injector…) and you will have support for everything (dvs, rotary encoders, loops… ) and send recorded audio from true live looping apps is just “two clicks” (with AudioShare in between if the source app can send directly to djplayer). Also it’s possible to read pendrives so you can even use sample from other source or export from the iDevice into other gear which reads pendrives.

Said that, I will love to see what you describe happening but after long time expecting someone makes it happen and studying alternatives that will be my suggestion.

audovoice, 2021-09-09:
The reality is that in DIY or Buy, the honest answer is almost never DIY. Economy of scale is so crushingly powerful. I think sc1000 manages to be a worthwhile DIY option. Mostly because highly portable doesn't seem to be common design choice. Also music gear in general gets less benefit from scale because it is more of a niche market.

That said, computers are handy for music, tablets are handy too, and used gear is out there and still works.

Good price of a raspberry pi 4 b 2gb is $35 if you can find it in stock. All other things being the same it does not change the price much. Adding a screen for ~$50 bucks minimum, and OR getting the 8gb pi for $75 moves the price of the whole thing much further into not worth it. I think fitting the screen into the lid of a hinge open wooden jewellery box off aliexpress is a good option for form factor. That or plastic, or aluminum junction boxes.

I am basically new to working with hardware. I am an OK programmer. Mostly I do just modify other peoples projects as a starting point to build off of. I am not that familiar with C.

I'd still like to try making the modification. I am guessing most of the code is intact and it would not be a monumental effort to make a sd card image for the pi 3 and pi 4. pideck as it is on github only works on pi 3 but can apparently be copied over to a pi 4 image. But I don't even own a pi 4 and their is a shortage of them.

I think this could possibly revitalize interest in developing pideck, and any feature developed over there has a good opportunity to be ported back to sc1000.

If you have the source code somewhere I would love to see it. If you don't have it handy or want to release it, some info on how you did it I am sure would go a long way. Like what class you modified. Where was sensor data being read. Like was it added to an existing thread or did it have its own.

DubbyLabby, 2021-09-09:
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

That’s what I said “old iPhone” (SE 1st gen are under 100€ second hand and older even cheaper). Also because software is done (and maintained by other).

>
> I am basically new to working with hardware. I am an OK programmer. Mostly I do just modify other peoples projects as a starting point to build off of. I am not that familiar with C.

I’m similar approach with hardware trying to avoid coding the most I can.

> I'd still like to try making the modification. I am guessing most of the code is intact and it would not be a monumental effort to make a sd card image for the pi 3 and pi 4. pideck as it is on github only works on pi 3 but can apparently be copied over to a pi 4 image. But I don't even own a pi 4 and their is a shortage of them.

I’m agree and if you are prone to code I encourage you to try it.

>
> I think this could possibly revitalize interest in developing pideck, and any feature developed over there has a good opportunity to be ported back to sc1000.

I thought the same when I proposed some improvements at their github but they aren’t interested in controllers, just timecode.

>
> If you have the source code somewhere I would love to see it. If you don't have it handy or want to release it, some info on how you did it I am sure would go a long way. Like what class you modified. Where was sensor data being read. Like was it added to an existing thread or did it have its own.

Rasteri’s code I’m pointing is all in this github we are talking at the moment. Did you check the folders? I have not extra code by myself but it seems you maybe get confused because I reply more than Rasteri. He has less time than me (stated by himself) and I’m fan of his work from old days of “scratch box controller” which was the sc1000 granpa.
Since I studied the project (alongside others) for my own projects (mostly unfinished or directly interest-lost) I try to help other users in its own journey (and wait Rasteri’s answers on its own too), that’s why I pointed to djplayer since there’s few people in dj field prone to code and/or share their code. Most djs are just users.

audovoice, 2021-09-11:
Its funny I just didn't see that software folder. pideck/xwax.c and SC1000/xwax.c are very different. I suspect they do largely the same things but there is so much more error checking that needs to be done on a PiDeck.
Its to the point where I wonder if it would be easier to change pideck to accept rotatory sensor input or change SC1000 so it has a gui again.
I am tempted to go with changing SC1000 as I think it would be easier and cleaner. But I'd like it to be able to record a loop off of a line in or internally and that means using Jack, which is already a part of how pideck works. It might be cleaner and easier to just write something new for recording a loop, using jack.
Anyway I will continue to look into this a bit more.

DubbyLabby, 2021-09-11:
AFAIK midi encoder was implemented for song browsing in piDeck but everytime someone ask for digital platter implementation they reject and point into mixxx direction. I also approached them for similar and other request but they have their own issues/roadmap so take some “patience pills”. It’s also a huge development project… maybe xwax will be better option for small improvements and it’s touch-friendly GUI…

https://github.com/pideck/pideck/issues/21

https://github.com/pideck/pideck/issues/42

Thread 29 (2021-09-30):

AUDIO OUTPUT

mag23rad, 2021-09-30:
Hi,
     .. does anyone know if it is possible to
                            split
 the beats and samples mixed audio output
                            into
2 mono signals (left = beats and right = samples)?

That would be useful.

PEACE

DubbyLabby, 2021-12-19:
You can do that panning stereo files. Just get beats files  panned into L and samples into R. Use audacity or similar audio editor and that’s it.

Idk if there’s a way to force it from code.

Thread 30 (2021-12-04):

Dedicated Midi Input - would be awesome!

mag23rad, 2021-12-04:
Does anyone know if adding a dedicated MIDI input would be difficult to implement?

DubbyLabby, 2021-12-19:
I think Andy has midi in/out on the roadmap (afair)

mglean, 2024-04-28:
I want to start looking at this soon, MIDI out too, maybe rotation info over midi?

DubbyLabby, 2024-04-29:
https://github.com/rasteri/SC1000/issues/19

01GOD, 2024-04-29:
Midi…input? For what?

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

DubbyLabby, 2024-04-29:
Midi input (and OSC) is implemented to a certain degree but for the jogwheel and crossfader aren’t. It could be useful for someone wanting to control the scratch from external controller and even implement 2 jog support (but only one mixed output since the board has only one audio stereo output).

For midi output check my other comment since I explained there my thoughts.

Let’s hope Andy see this activity and surprise us with some news…

SaccoSVD, 2024-11-13:
The SC1000MK2 comes with "MIDI support (Limited)"

I wonder if it was implemented by Rasteri himself.

mglean, 2024-11-13:
I have never been able to get it working. Midi note input would is still
desired here. ;)

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

--
ILYIASFMTY

rasteri, 2024-11-13:
Yeah MIDI input works but it doesn't support crossfader or jog - https://www.youtube.com/watch?v=4zC_MFa_150

Perhaps in a future revision

SaccoSVD, 2024-11-13:
Ah. My bad. I was talking about MIDI via USB.

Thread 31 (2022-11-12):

Is so quiet over here.

SaccoSVD, 2022-11-12:
:(

Would be so nice at some point, to have some of the features we've discussed.

DubbyLabby, 2023-04-13:
Probably chip shortage didn’t help.
I have all my prototyping in stand by and all the help I can offer was done. If someday I learn c++ (or chatgpt maybe) I will love to contribute further but…

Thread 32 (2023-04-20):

MCP23017 connection in new firmware

koitzroller, 2023-04-20:
Hi folks!

I tried to connect a MCP23017 as [Rasteri said in his wiki](http://rasteri.com/SC1000_MCP23017_Connection_Diagram.pdf) in a SC1000MK2 from Portablismgear, but nothing occurs. Tried to add # to comment lines in scsettings.txt with input conflict (gpio=1,15 and 16) but no results. It seems MCP23017 address board is 000, right? I even explore code to check if is hardwired to other port, but I didn't find it. Any thoughts?

Regards

DubbyLabby, 2023-04-21:
Are you running the latest firmware?
http://rasteri.com/wiki/SC1000_Firmware_Update

koitzroller, 2023-04-23:
Yes, I'm running the last firmware.

Finally I discovered the problem: by default MCP23017 board I'm using (Waveshare) is on 111 address w/o solder pins instead of 000 needed by SC1000 🤦‍♂️.

Now works flawlessly.

Regards

Closed 2023-04-23.

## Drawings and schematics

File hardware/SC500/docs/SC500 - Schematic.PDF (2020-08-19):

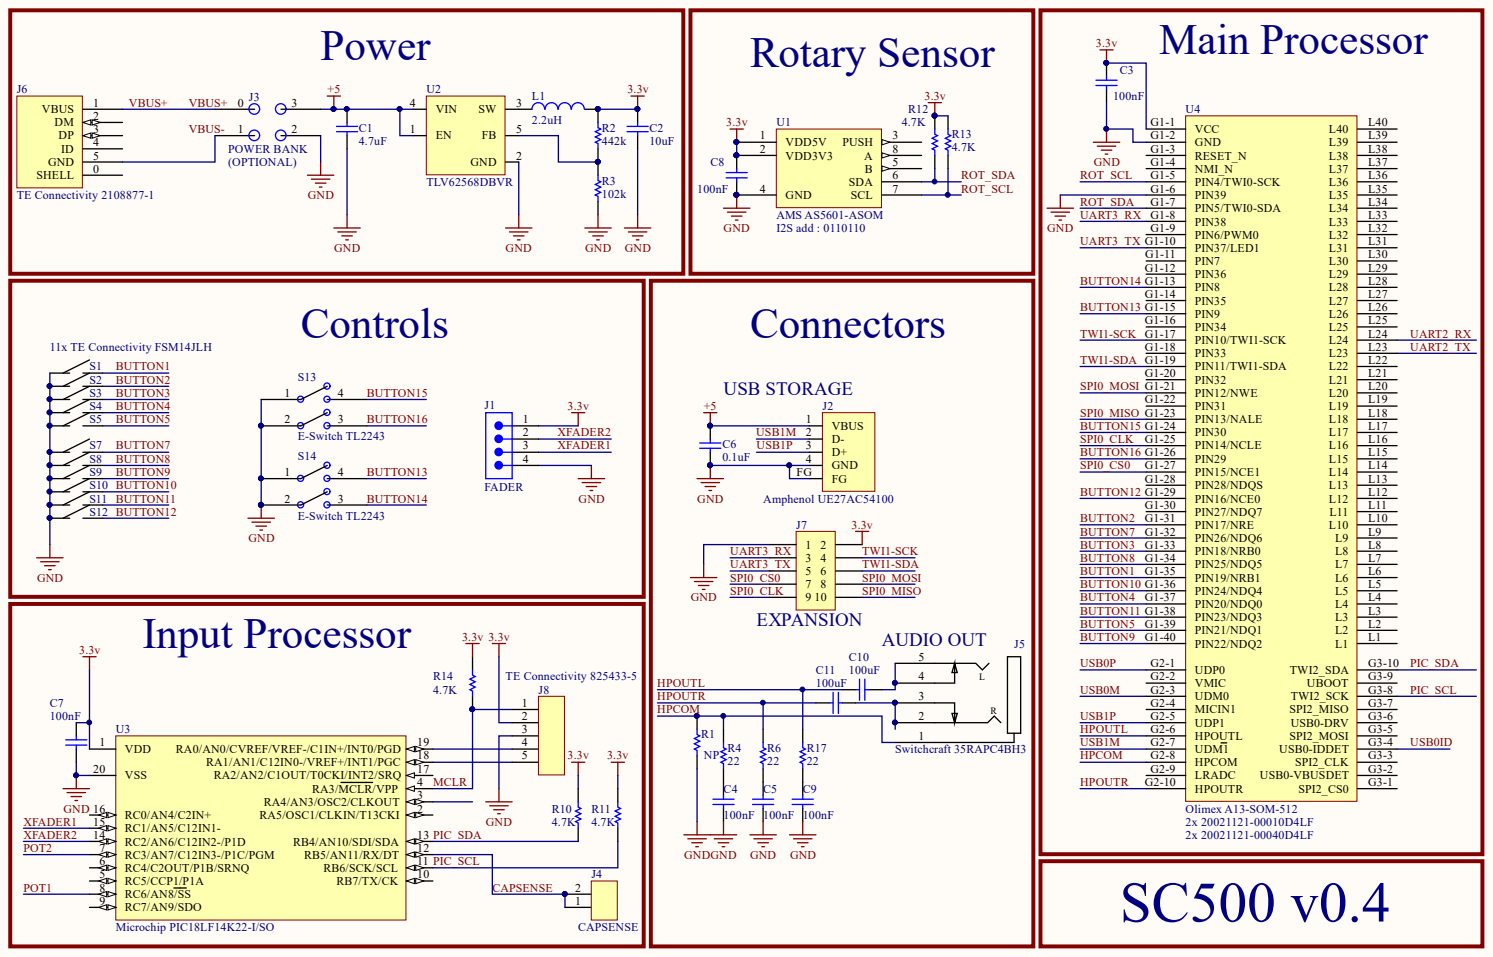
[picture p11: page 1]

18 RA0/AN0/CVREF/VREF-/C1IN+/INT0/PGD 19 7 RA1/AN1/C12IN0-/VREF+/INT1/PGC

1 | MCL R

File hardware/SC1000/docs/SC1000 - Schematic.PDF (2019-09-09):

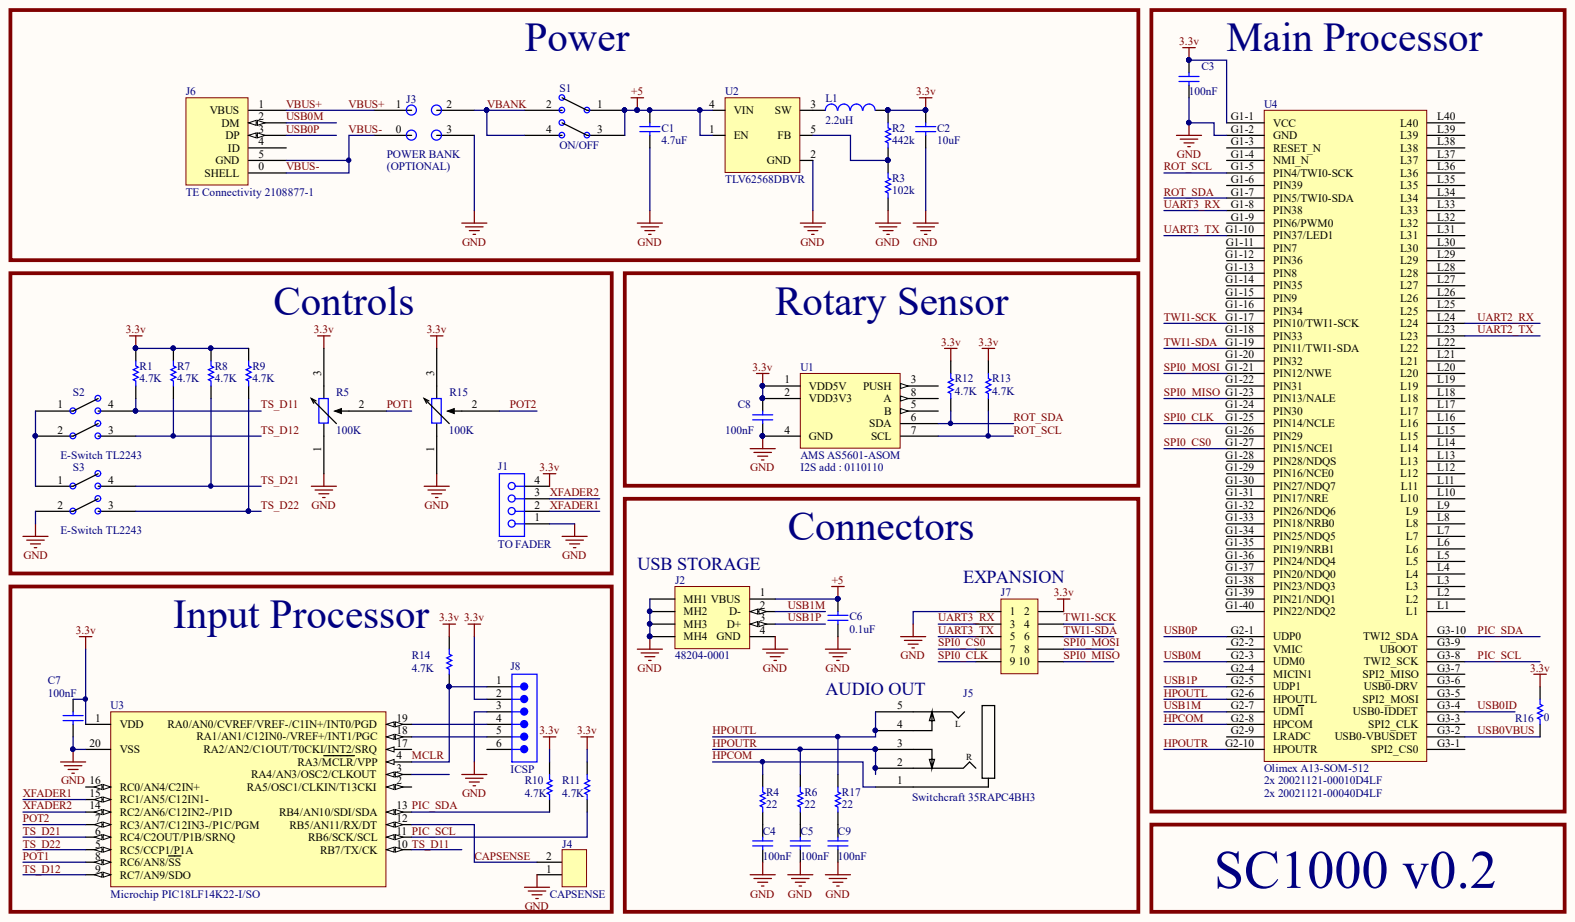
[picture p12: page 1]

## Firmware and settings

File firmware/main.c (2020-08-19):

/*
 * Copyright (C) 2018 Andrew Tait <rasteri@gmail.com>
 *
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
 */
 
 
#include <xc.h>
#include "mcc_generated_files/mcc.h"

void I2C_Slave_Init(short address) {
    SSPSTAT = 0b10000000;
    SSPADD = address; //Setting address
    SSPCON1 = 0b00110110; // Enabled, No clock stretching, I2C Slave, 7bit address
    SSPCON2 = 0x01;


    SSPIF = 0; // Clear the serial port interrupt flag
    BCLIF = 0; // Clear the bus collision interrupt flag
    BCLIE = 1; // Enable bus collision interrupts
    SSPIE = 1; // Enable serial port interrupts
    PEIE = 1; // Enable peripheral interrupts
    GIE = 1; // Enable global interrupts
}

unsigned int index_i2c = 0; // used as an index pointer in array
unsigned char junk = 0; // used to place unnecessary data
unsigned char first = 1; // used to determine whether data address 

volatile unsigned char STATUSDATA[] = {0, 0, 0, 0, 0, 0, 0, 0};

void __interrupt () ISR(void) {
    if (SSPIF) // check to see if SSP interrupt
    {
        if (SSPSTATbits.R_nW) { // Master read (R_nW = 1)
            junk = SSPBUF;
            SSPBUF = STATUSDATA[index_i2c];
            SSPCON1bits.CKP = 1; // Release CLK
        }
        if (!SSPSTATbits.R_nW) { //  Master write (R_nW = 0)

            if (!SSPSTATbits.D_nA) { // Last byte was an address (D_nA = 0)
                first = 1; //last byte was address, next will be data location
                junk = SSPBUF; // read buffer to clear BF
                SSPCON1bits.CKP = 1; // Release CLK
            }
            if (SSPSTATbits.D_nA) // Last byte was data (D_nA = 1)
            {
                if (first) {
                    index_i2c = SSPBUF; // load index with array location
                    first = 0; // now clear this
                } else {
                    junk = SSPBUF; // Master did two data writes, could use this to send data to pic, maybe capsense calibration data
                }

                if (SSPCON1bits.WCOL) { // Did a write collision occur?

                    SSPCON1bits.WCOL = 0; //  clear WCOL
                    junk = SSPBUF; // dummy read to clear BF bit
                }
                SSPCON1bits.CKP = 1; // Release CLK
            }
        }
    }
    if (BCLIF) // Did a bus collision occur?
    {

        junk = SSPBUF; // dummy read SSPBUF to clear BF bit
        BCLIF = 0; // clear bus collision Int Flag bit
        SSPCON1bits.CKP = 1; // Release CLK
    }
    SSPIF = 0; // clear SSPIF flag bit
}

unsigned int getADC(unsigned char channel) {

    ADCON0bits.CHS = channel;
    ADCON0bits.ADON = 1;
    __delay_us(40);
    ADCON0bits.GO_DONE = 1;
    while (ADCON0bits.GO_DONE);
    return ((signed int) ADRESH << 8) | ADRESL;
}

void main(void) {

    char touchState = 0;
    char calibrationMode = 1;
    unsigned int calibrationCount;
    float threshold = 1023.0;
    unsigned int touchedNum = 0;
    unsigned int tmp1, tmp2, tmp3, tmp4, tmp5;
    float touchAverage = 1023.0;
    unsigned int touchAverageInt = 0, thresholdInt = 0;;

    // Initialize the device
    SYSTEM_Initialize();

    PORTA = 0;
    LATA = 0;
    PORTB = 0;
    LATB = 0;
    PORTC = 0;
    LATC = 0;

    TRISB4 = 1; //I2C SDA
    TRISB5 = 1; //Capsense
    TRISB6 = 1; //I2C SCL
    TRISB7 = 1; //TS_D11
    TRISC0 = 0; //Dummy pin for capsense charge
    TRISC1 = 1; //XFADER1
    TRISC2 = 1; //XFADER2
    TRISC3 = 1; //POT2
    TRISC4 = 1; //TS_D21
    TRISC5 = 1; //TS_D22
    TRISC6 = 1; //POT1
    TRISC7 = 1; //TS_D12

    RC0 = 1;

    ANSEL = 0b10000000; //AN7/RC3 is analog
    ANSELH = 0b00000001; //AN8/RC6 is analog

    /* 16Tosc conversion clock, 6Tad acquisition time, ADC Result Right Justified */
    ADCON2 = 0b10011101;

    I2C_Slave_Init(0xD2);

    // Delay while we wait for everything to settle
    for (calibrationCount = 0; calibrationCount < 60000; calibrationCount++);

    
    threshold = 1023.0;
    
    calibrationCount = 0;
    while (1) {

        tmp1 = getADC(5);
        tmp2 = getADC(6);
        tmp3 = getADC(7);
        tmp4 = getADC(8);

        // Charge the internal capacitor by pointing it at a dummy pin we know is set to VDD (RC0/AN4)-
        RC0 = 1;
        ADCON0bits.CHS = 4;

        // Ground Sensor to discharge any residual charge
        TRISB5 = 0;
        ANSELHbits.ANS11 = 0;
        RB5 = 0;

        // Now make it an input and get result
        TRISB5 = 1;
        tmp5 = getADC(11);
        #define ALPHA 0.01
        touchAverage = (ALPHA * tmp5) + (1.0 - ALPHA) * touchAverage;

        // First 3000 readings are to calibrate the threshold
        if (calibrationMode) {

            if (touchAverage < threshold)
                threshold = touchAverage;

            calibrationCount++;
            if (calibrationCount > 3000) {
                calibrationMode = 0;
                threshold -= 100; // Give ourselves some margin
            }

        } else {
            
            if (touchState) {
                if (touchAverage > threshold)
                    touchedNum++;
                else
                    touchedNum = 0;

                // Require 200 above-threshold readings before we consider the platter released
                if (touchedNum > 20) {
                    touchState = 0;
                    touchedNum = 0;
                }

            } else {
                if (touchAverage <= threshold)
                    touchedNum++;
                else
                    touchedNum = 0;

                if (touchedNum > 20) {
                    touchState = 1;
                    touchedNum = 0;
                }

            }

        }
        
        // ADC LSBs
        STATUSDATA[0] = (unsigned char) (tmp1 & 0xFF);
        STATUSDATA[1] = (unsigned char) (tmp2 & 0xFF);
        STATUSDATA[2] = (unsigned char) (tmp3 & 0xFF);
        STATUSDATA[3] = (unsigned char) (tmp4 & 0xFF);

        // ADC MSBs
        STATUSDATA[4] = (unsigned char) (((tmp1 & 0x300) >> 8) | ((tmp2 & 0x300) >> 6) | ((tmp3 & 0x300) >> 4) | ((tmp4 & 0x300) >> 2));

        // Digital I/Os and capsense
        STATUSDATA[5] = (unsigned char) ((PORTBbits.RB7) | (PORTCbits.RC7 << 1) | (PORTCbits.RC4 << 2) | (PORTCbits.RC5 << 3) | touchState << 4);
        
        touchAverageInt = (unsigned int)touchAverage;
        STATUSDATA[6] = (unsigned char) (touchAverageInt & 0xFF);
        STATUSDATA[7] = (unsigned char) ((touchAverageInt & 0x300) >> 8);
    }
}
/**
 End of File
 */

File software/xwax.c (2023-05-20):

/*
 * Copyright (C) 2018 Mark Hills <mark@xwax.org>
 *
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
 */

#include <assert.h>
#include <locale.h>
#include <stdio.h>
#include <stdlib.h>
#include <string.h>
#include <unistd.h>
#include <sys/mman.h> /* mlockall() */

#include <unistd.h>		   //Needed for I2C port
#include <fcntl.h>		   //Needed for I2C port
#include <sys/ioctl.h>	   //Needed for I2C port
#include <linux/i2c-dev.h> //Needed for I2C port
#include <time.h>
#include <dirent.h>
#include <stdint.h>
#include <string.h>
#include <signal.h>

#include "alsa.h"
#include "controller.h"
#include "device.h"
#include "dummy.h"
#include "realtime.h"
#include "thread.h"
#include "rig.h"
#include "track.h"
#include "xwax.h"
#include "sc_input.h"
#include "sc_midimap.h"
#include "dicer.h"

#define DEFAULT_IMPORTER EXECDIR "/xwax-import"

struct deck deck[2];

struct rt rt;

static const char *importer;

SC_SETTINGS scsettings;

struct mapping *maps = NULL;

unsigned int countChars(char *string, char c)
{
	unsigned int count = 0;
	
	//printf("Checking for commas in %s\n", string);

	do
	{
		if ((*string) == c)
		{
			count++;
		}
	} while ((*(string++)));
	return count;
}

void loadSettings()
{
	FILE *fp;
	char *line = NULL;
	size_t len = 0;
	ssize_t read;
	char *param, *actions;
	char *value;
	unsigned char channel = 0, notenum = 0, controlType = 0, pin = 0, pullup = 0, port = 0;
	char edge;
	char delim[] = "=";
	char delimc[] = ",";
	unsigned char midicommand[3];
	char *linetok, *valuetok;
	// set defaults
	scsettings.buffersize = 256;
	scsettings.faderclosepoint = 2;
	scsettings.faderopenpoint = 10;
	scsettings.platterenabled = 1;
	scsettings.platterspeed = 2275;
	scsettings.samplerate = 48000;
	scsettings.updaterate = 2000;
	scsettings.debouncetime = 5;
	scsettings.holdtime = 100;
	scsettings.slippiness = 200;
	scsettings.brakespeed = 3000;
	scsettings.pitchrange = 50;
	scsettings.mididelay = 5;
	scsettings.volAmount = 0.03;
	scsettings.volAmountHeld = 0.001;
	scsettings.initialVolume = 0.125;
	scsettings.midiRemapped = 0;
	scsettings.ioRemapped = 0;
	scsettings.jogReverse = 0;
	scsettings.cutbeats = 0;

	// later we'll check for sc500 pin and use it to set following settings
	scsettings.disablevolumeadc = 0;
	scsettings.disablepicbuttons = 0;

	// Load any settings from config file
	fp = fopen("/media/sda/scsettings.txt", "r");
	if (fp == NULL)
	{
		// load internal copy instead
		fp = fopen("/var/scsettings.txt", "r");
	}


	if (fp != NULL)
	{
		while ((read = getline(&line, &len, fp)) != -1)
		{
			if (strlen(line) < 2 || line[0] == '#')
			{ // Comment or blank line
			}
			else
			{
				param = strtok_r(line, delim, &linetok);
				value = strtok_r(NULL, delim, &linetok);

				if (strcmp(param, "buffersize") == 0)
					scsettings.buffersize = atoi(value);
				else if (strcmp(param, "faderclosepoint") == 0)
					scsettings.faderclosepoint = atoi(value);
				else if (strcmp(param, "faderopenpoint") == 0)
					scsettings.faderopenpoint = atoi(value);
				else if (strcmp(param, "platterenabled") == 0)
					scsettings.platterenabled = atoi(value);
				else if (strcmp(param, "disablevolumeadc") == 0)
					scsettings.disablevolumeadc = atoi(value);
				else if (strcmp(param, "platterspeed") == 0)
					scsettings.platterspeed = atoi(value);
				else if (strcmp(param, "samplerate") == 0)
					scsettings.samplerate = atoi(value);
				else if (strcmp(param, "updaterate") == 0)
					scsettings.updaterate = atoi(value);
				else if (strcmp(param, "debouncetime") == 0)
					scsettings.debouncetime = atoi(value);
				else if (strcmp(param, "holdtime") == 0)
					scsettings.holdtime = atoi(value);
				else if (strcmp(param, "slippiness") == 0)
					scsettings.slippiness = atoi(value);
				else if (strcmp(param, "brakespeed") == 0)
					scsettings.brakespeed = atoi(value);
				else if (strcmp(param, "pitchrange") == 0)    
					scsettings.pitchrange = atoi(value);
				else if (strcmp(param, "jogreverse") == 0)
					scsettings.jogReverse = atoi(value);
				else if (strcmp(param, "cutbeats") == 0)
					scsettings.cutbeats = atoi(value);
				else if (strstr(param, "midii") != NULL)
				{
					scsettings.midiRemapped = 1;
					controlType = atoi(strtok_r(value, delimc, &valuetok));
					channel = atoi(strtok_r(NULL, delimc, &valuetok));
					notenum = atoi(strtok_r(NULL, delimc, &valuetok));
					edge = atoi(strtok_r(NULL, delimc, &valuetok));
					actions = strtok_r(NULL, delimc, &valuetok);

					//255 means bind to all notes
					if (notenum == 255){

						// Build MIDI command
						midicommand[0] = (controlType << 4) | channel;
						midicommand[1] = notenum;
						midicommand[2] = 0;

						char tempact[20];
						for (midicommand[1] = 0; midicommand[1] < 128; midicommand[1]++){
							sprintf(tempact, "%s%u", actions, midicommand[1]);
							add_config_mapping(
								&maps,
								MAP_MIDI,
								midicommand,
								0,
								0,
								0,
								edge,
								tempact);
						}
					}
					// otherwise just bind to one note
					else {
						// Build MIDI command
						midicommand[0] = (controlType << 4) | channel;
						midicommand[1] = notenum;
						midicommand[2] = 0;
						add_config_mapping(
							&maps,
							MAP_MIDI,
							midicommand,
							0,
							0,
							0,
							edge,
							actions);
					}
				}
				else if (strstr(param, "io") != NULL)
				{
					scsettings.ioRemapped = 1;
					unsigned int commaCount = countChars(value, ',');
					//printf("Found io %s - comacount %d\n", value, commaCount);
					port = 0;
					if (commaCount == 4){
						port = atoi(strtok_r(value, delimc, &valuetok));
						pin = atoi(strtok_r(NULL, delimc, &valuetok));
					}
					else {
						pin = atoi(strtok_r(value, delimc, &valuetok));
					}
					pullup = atoi(strtok_r(NULL, delimc, &valuetok));
					edge = atoi(strtok_r(NULL, delimc, &valuetok));
					actions = strtok_r(NULL, delimc, &valuetok);
					add_config_mapping(
						&maps,
						MAP_IO,
						NULL,
						port,
						pin,
						pullup,
						edge,
						actions);
				}
				else if (strcmp(param, "mididelay") == 0) // Literally just a sleep to allow USB devices longer to initialize
					scsettings.mididelay = atoi(value);
				else
				{
					printf("Unrecognised configuration line - Param : %s , value : %s\n", param, value);
				}
			}
		}
	}

	

	printf("bs %d, fcp %d, fop %d, pe %d, ps %d, sr %d, ur %d\n",
		   scsettings.buffersize,
		   scsettings.faderclosepoint,
		   scsettings.faderopenpoint,
		   scsettings.platterenabled,
		   scsettings.platterspeed,
		   scsettings.samplerate,
		   scsettings.updaterate);

	if (fp)
		fclose(fp);
	if (line)
		free(line);
}

void sig_handler(int signo)
{
	if (signo == SIGINT)
	{
		printf("received SIGINT\n");
		exit(0);
	}
}
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

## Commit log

2018-11-05 removed SPI/MCP3008 functions, code cleanup
2018-11-06 Main processor I2C code to interface with the input processor
2018-11-09 Added contiually-variable pitch in build_pcm routine
2018-11-12 new capacitive touch algorithm
2018-11-20 Added hardware files
    [BACK.GBL, BACK.GBO, BACK.GBS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]
2018-11-21 moved some stuff around
    [JogWheel.GBL, JogWheel.GBO, JogWheel.GBS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]
2018-12-06 Updated Main PCB gerbers/BOM
    [PCB2.GBL, PCB2.GBS, PCB2.GTL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]
2018-12-14 Added enclosure/Main PCB STEP files
    [backplate.step, bottomplate.step, frontplate.step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]
2018-12-14 Added gerbers for Bottom/Front/Side plates
    [BOTTOMPLATE.GBL, BOTTOMPLATE.GBO, BOTTOMPLATE.GBS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]
2018-12-15 Updated hardware files/BOM
    [SC1000 - Bill Of Materials.xlsx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]
2018-12-19 Added centroid file, various manufacturability fixes
    [SC1000 - Bill Of Materials.xlsx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]
2019-02-14 more button mapping bugfixes
    [sc_input.c]
2019-05-03 Fixed sdcard image for different olimex board revision
    [main.c]
2019-09-09 fixes : horrible noises, fader hysteresis, sticker drift
    [player.c, sc_input.c, xwax.c]
2019-09-09 Added filters to main board, mod board for existing boards
    [PCB2.GBL, PCB2.GBP, PCB2.GBS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]
2019-09-10 Disabled rotary sensor filter/hysteresis, increased polling rate
2019-09-17 broken implementation of input buffer
    [deck.c, player.c, realtime.c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]
2019-09-17 Slightly less broken implementation of input buffer
    [player.c, sc_input.c, xwax.c]
2019-09-23 Slightly more broken implementation of input buffer
    [rotout.csv]
2019-09-24 Even more broken implementation of input buffer
    [player.c]
2019-09-27 Input playback for testing
    [rotout.csv]
2019-09-29 Crappy filter attempt
2019-09-30 better filter attempt
2019-10-25 Added pitch control, MIDI bugfixes
    [deck.c, player.c, realtime.c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]
2019-10-29 added simple filter
2019-11-06 started implementing cue point buttons
2019-11-11 Start/Stop buttons, Saturating mixer
2019-11-11 Added brake time adjustment
2019-11-13 Fixed ground error on PCB
    [PCB2.GBL, PCB2.GBS, PCB2.GTL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]
2019-11-13 bumped up board rev
    [PCB2.GBL, PCB2.GBS, PCB2.GTL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]
2019-11-14 MIDI pitch bend, default mappings
2019-11-20 Fixed default MIDI mapping
    [xwax.c]
2019-12-19 Mapping for membrane switches, skip folder bugfixes
    [player.c, sc_input.c]
2019-12-29 yet more USB midi hotplug fixes
    [sc_input.c]
2019-12-29 more USB hotplug fixes
    [sc_input.c]
2019-12-29 Disabled MIDI hotplug, replaced with 10sec delay
    [sc_input.c]
2020-03-01 Perfect sample looping
2020-06-17 Unified button processing, input thread refactor
2020-06-19 additional button actions
2020-08-14 IO mappings for new SC500 board rev
2020-08-18 Lots of MIDI fixes
    [sc_input.c, xwax.c]
2020-08-19 SC500 CAM documents
    [BACK.GBL, BACK.GBO, BACK.GBS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]
2020-08-19 SC500 BOM
    [SC500 - Bill Of Materials.xlsx]
2020-08-19 Added SC500 schematic, OS version message
2020-08-21 SC500 enclosure gerbers/STL/STEP
    [BACKPLATE.step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]
2020-08-21 updater updates, SC500 bugfixes
    [sc_input.c]
2020-08-30 Silly MIDI mapping bug
    [sc_input.c, xwax.c]
2020-08-30 fix makefile + annoying debug messages
    [sc_input.c]
2020-08-30 fix default I2C GPIO mappings
    [sc_input.c]
2020-09-01 Updated enclosure CAM files, added lemur preset
    [BACK.GBL, BACK.GBS, BACK.GTL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]
2020-09-24 fader hysteresis fixes, broken laser implementation
    [player.c, sc_input.c, xwax.c]
2020-09-24 Better backspin/laser handling
2020-09-25 Reverse platter mode, various bugfixes
    [deck.c, sc_input.c, xwax.c]
2020-10-12 fixed stupid jogwheel bug
    [sc_input.c]
2020-10-12 more stupid jogwheel bugs
    [player.c, sc_input.c]
2020-11-11 J7 mapping fixes, updater update
    [sc_input.c]
2021-02-04 Hopefully fixed MIDI mapping and added complete lemur map example
    [xwax.c]
2021-05-13 Option to cut beats with fader
2021-05-13 temp pitch bend, no sticker drift on pause, cut beats with fader,
    [deck.c, player.c, sc_input.c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]
